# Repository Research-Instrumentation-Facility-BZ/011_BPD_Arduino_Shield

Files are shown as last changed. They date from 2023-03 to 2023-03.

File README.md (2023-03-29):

Arduino Shield to control the BuckPuck High Power LEDs driver 3023-D-E-700 for optogenetic stimulation

based on :



Supplementary Figure 1, (e) Electric circuit diagram for the LED controller. This circuit was built on a custom Arduino shield. With the Arduino program (downloadable from the online version of this paper), this electric circuit controls high power LEDs. Intensity, pulse width, pulse frequency, length of pulse train, and the number of and interval between repeated pulse trains are controllable for up to 8 of 700 mA LEDs in parallel.
nagaki, H., Jung, Y., Hoopfer, E. et al. Optogenetic control of Drosophila using a red-shifted channelrhodopsin reveals experience-dependent influences on courtship. Nat Methods 11, 325–332 (2014). https://doi.org/10.1038/nmeth.2765

Components: 
PNP transistor : DXT3906-13 (SOT-89-3)

Diodes : VS-20L15TSTRL-M3 (TO-263AB)

IR LED : SFH 4050-Z (0603)

Resistors and capacitors : 100Ohm, 1KOhm, 1uF (1206)

v1: 
SRM20 + oven at 140/60/150/120 + drilling of 1.1, rivets of 0.8mm 
The isolation traces are very thin, and the thermal pad of the diodes is too small. It is impossible to solder the diodes.



v1.1:
Isolation traces are doubled, forced isolation between pads, and additional isolation contour around pads. 
The pads are bigger. The components can be soldered easily.
But the dircuit does not work. The leds are on all the time. I don't know if it comes from the circuit itself or from the power supply that drops at 3V all the time (should stay at 24V).



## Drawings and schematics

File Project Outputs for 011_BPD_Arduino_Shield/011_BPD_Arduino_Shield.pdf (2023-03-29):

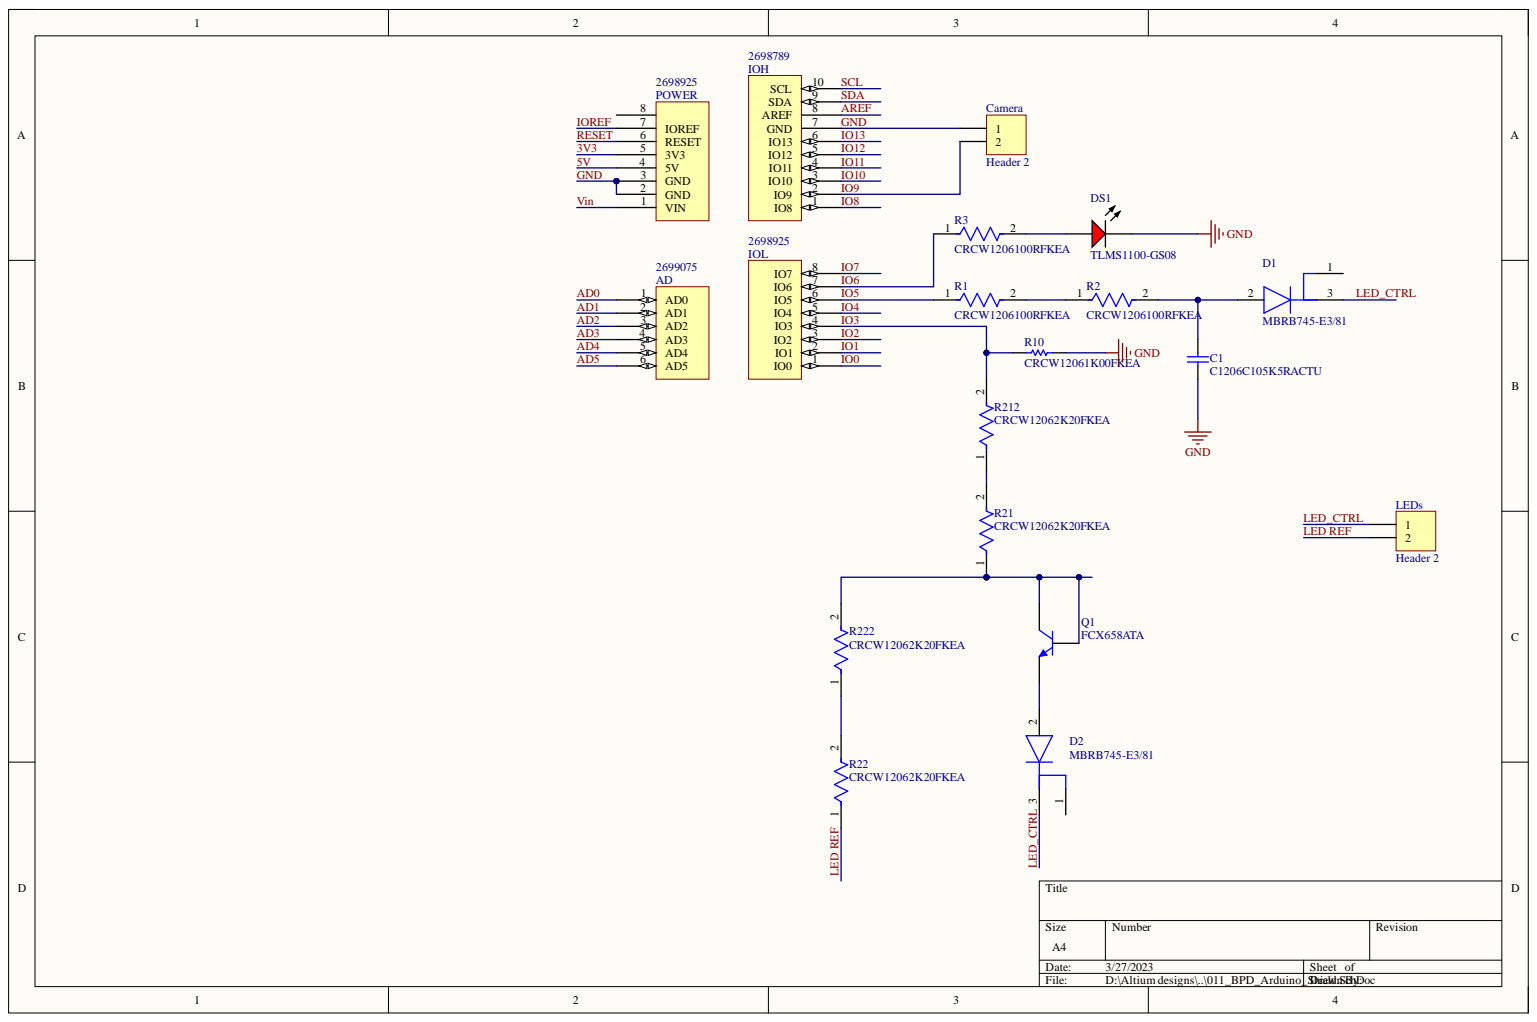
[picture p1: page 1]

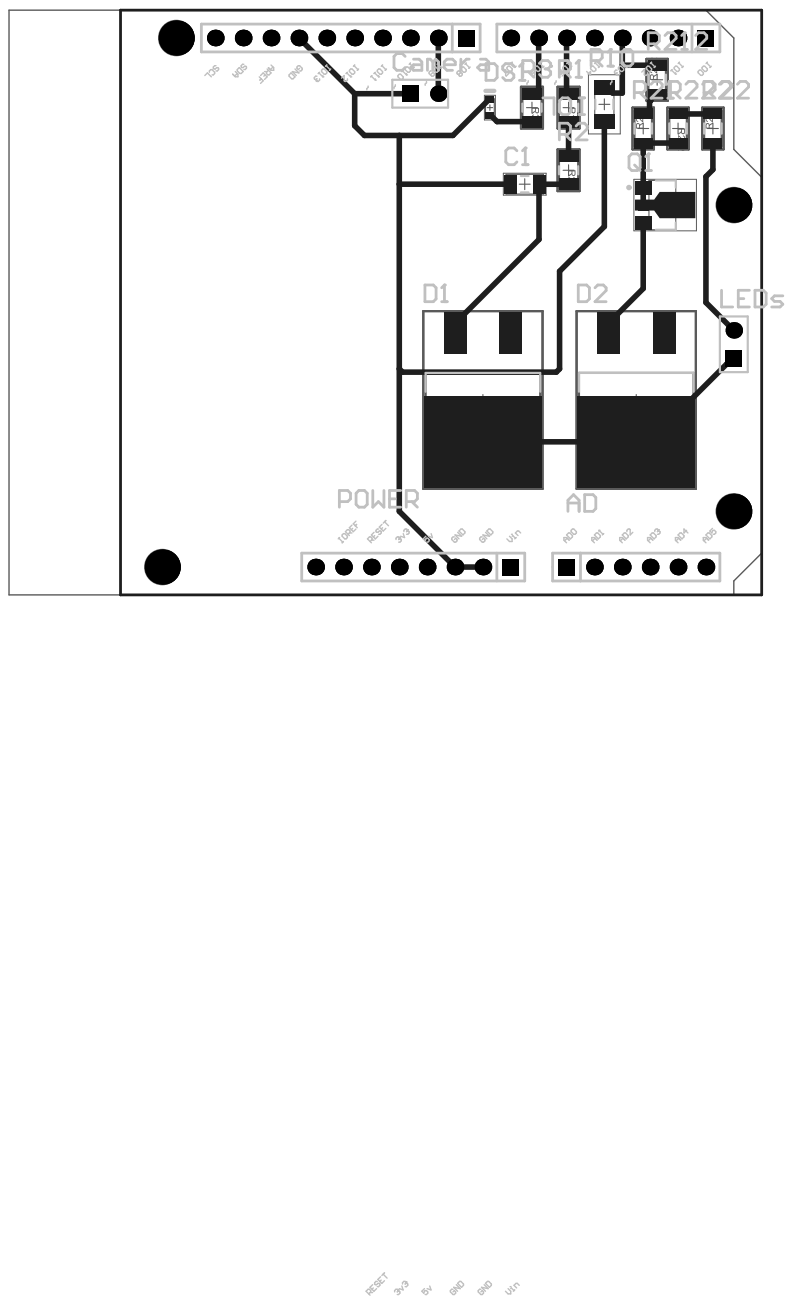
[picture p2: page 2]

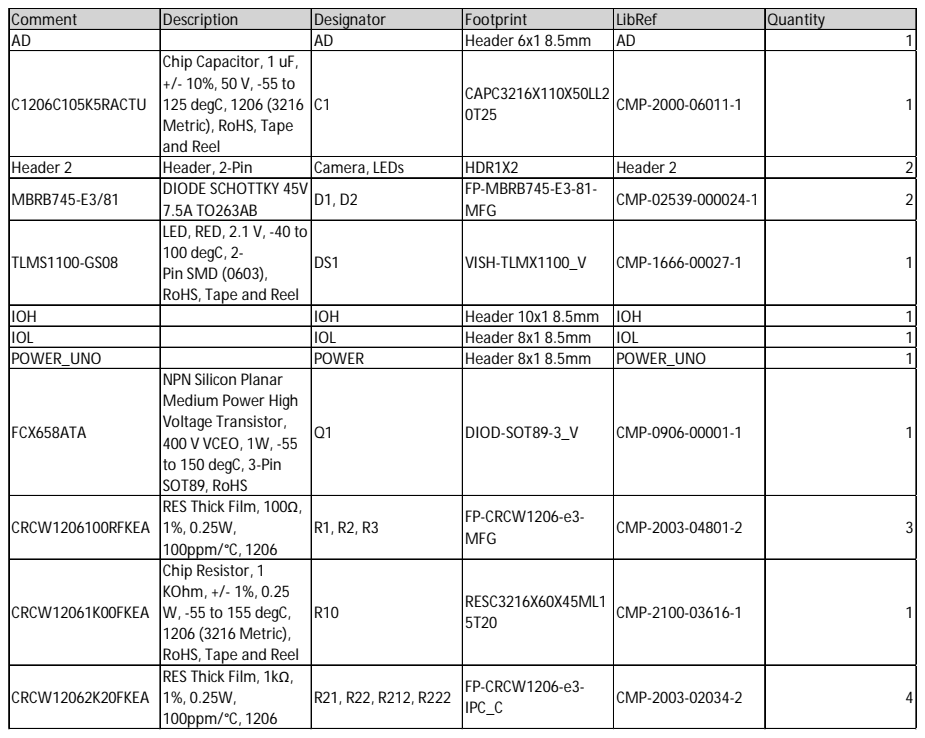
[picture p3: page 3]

Comment | Description | Designator | Footprint | LibRef | Quantity
AD | | AD | Header 6x1 8.5mm | AD | 1
C1206C105K5RACTU | Chip Capacitor, 1 uF, +/- 10%, 50 V, -55 to 125 degC, 1206 (3216 Metric), RoHS, Tape and Reel | C1 | CAPC3216X110X50LL2 0T25 | CMP-2000-06011-1 | 1

Header 2 | Header, 2-Pin | Camera, LEDs | HDR1X2 | Header 2 | 2
MBRB745-E3/81 | DIODE SCHOTTKY 45V 7.5A TO263AB | D1, D2 | FP-MBRB745-E3-81-MFG | CMP-02539-000024-1 | 2

TLMS1100-GS08 | LED, RED, 2.1 V, -40 to 100 degC, 2-Pin SMD (0603), RoHS, Tape and Reel | DS1 | VISH-TLMX1100_V | CMP-1666-00027-1 | 1

IOH | | IOH | Header 10x1 8.5mm | IOH | 1
IOL | | IOL | Header 8x1 8.5mm | IOL | 1
POWER_UNO | | POWER | Header 8x1 8.5mm | POWER_UNO | 1
FCX658ATA | NPN Silicon Planar Medium Power High Voltage Transistor, 400 V VCEO, 1W, -55 to 150 degC, 3-Pin SOT89, RoHS | Q1 | DIOD-SOT89-3_V | CMP-0906-00001-1 | 1

CRCW1206100RFKEA | RES Thick Film, 100Ω, 1%, 0.25W, 100ppm/°C, 1206 | R1, R2, R3 | FP-CRCW1206-e3-MFG | CMP-2003-04801-2 | 3

CRCW12061K00FKEA | Chip Resistor, 1 KOhm, +/- 1%, 0.25 W, -55 to 155 degC, 1206 (3216 Metric), RoHS, Tape and Reel | R10 | RESC3216X60X45ML1 5T20 | CMP-2100-03616-1 | 1

CRCW12062K20FKEA | RES Thick Film, 1kΩ, 1%, 0.25W, 100ppm/°C, 1206 | R21, R22, R212, R222 | FP-CRCW1206-e3-IPC_C | CMP-2003-02034-2 | 4

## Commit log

2023-03-27 initial release
    [011_BPD_Arduino_Shield.PcbDoc, 011_BPD_Arduino_Shield.PrjPcb, 011_BPD_Arduino_Shield.SchDoc]
2023-03-27 replace R2.2K with R1K (in stock)
    [011_BPD_Arduino_Shield.PcbDoc, 011_BPD_Arduino_Shield.SchDoc]
2023-03-27 redefinied board shape
    [011_BPD_Arduino_Shield.PcbDoc]
2023-03-27 routed ground with tracks
    [011_BPD_Arduino_Shield.PcbDoc, 011_BPD_Arduino_Shield.SchDoc]
